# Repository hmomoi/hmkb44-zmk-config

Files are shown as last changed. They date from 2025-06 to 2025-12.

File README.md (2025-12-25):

# hmkb44 のページ

44キーのキーボード「hmkb44」の作成資材のページです。

主に、zmkファームウェアの管理と、KiCadの設計資材をおいています。

# 目指すキーボード
* 40%キーボード（EPOMAKER TH40を参考に）
* Bluetoothで接続
* LEDチカチカ
* charlieplexの実験

このくらいを目指して作ってます。
seeeduino_xiao_ble を使ってイロイロ実験してみたくて作成しました。
# レイアウト


# 回路


# 参照したnote
* https://note.com/pooh_polo/n/n2a34a922b4c8 (zmk firmwareの書き方)

# 参照したgithub
* https://github.com/te9no/zmk-config-GeaconSolstice/blob/main/boards/shields/GeaconSolstice/Solstice.keymap
* https://github.com/mctechnology17/zmk-config
* https://github.com/te9no/zmk-config-title72 （charlieplexのダイオードの向きが逆）
* https://github.com/HookyKB/round-robin-schematics (charlieplexのschematicが公開されている)
* https://github.com/mentako-ya/zmk-config-mtk64/tree/master (Layer rgbled widget を参考)

# キーマップ


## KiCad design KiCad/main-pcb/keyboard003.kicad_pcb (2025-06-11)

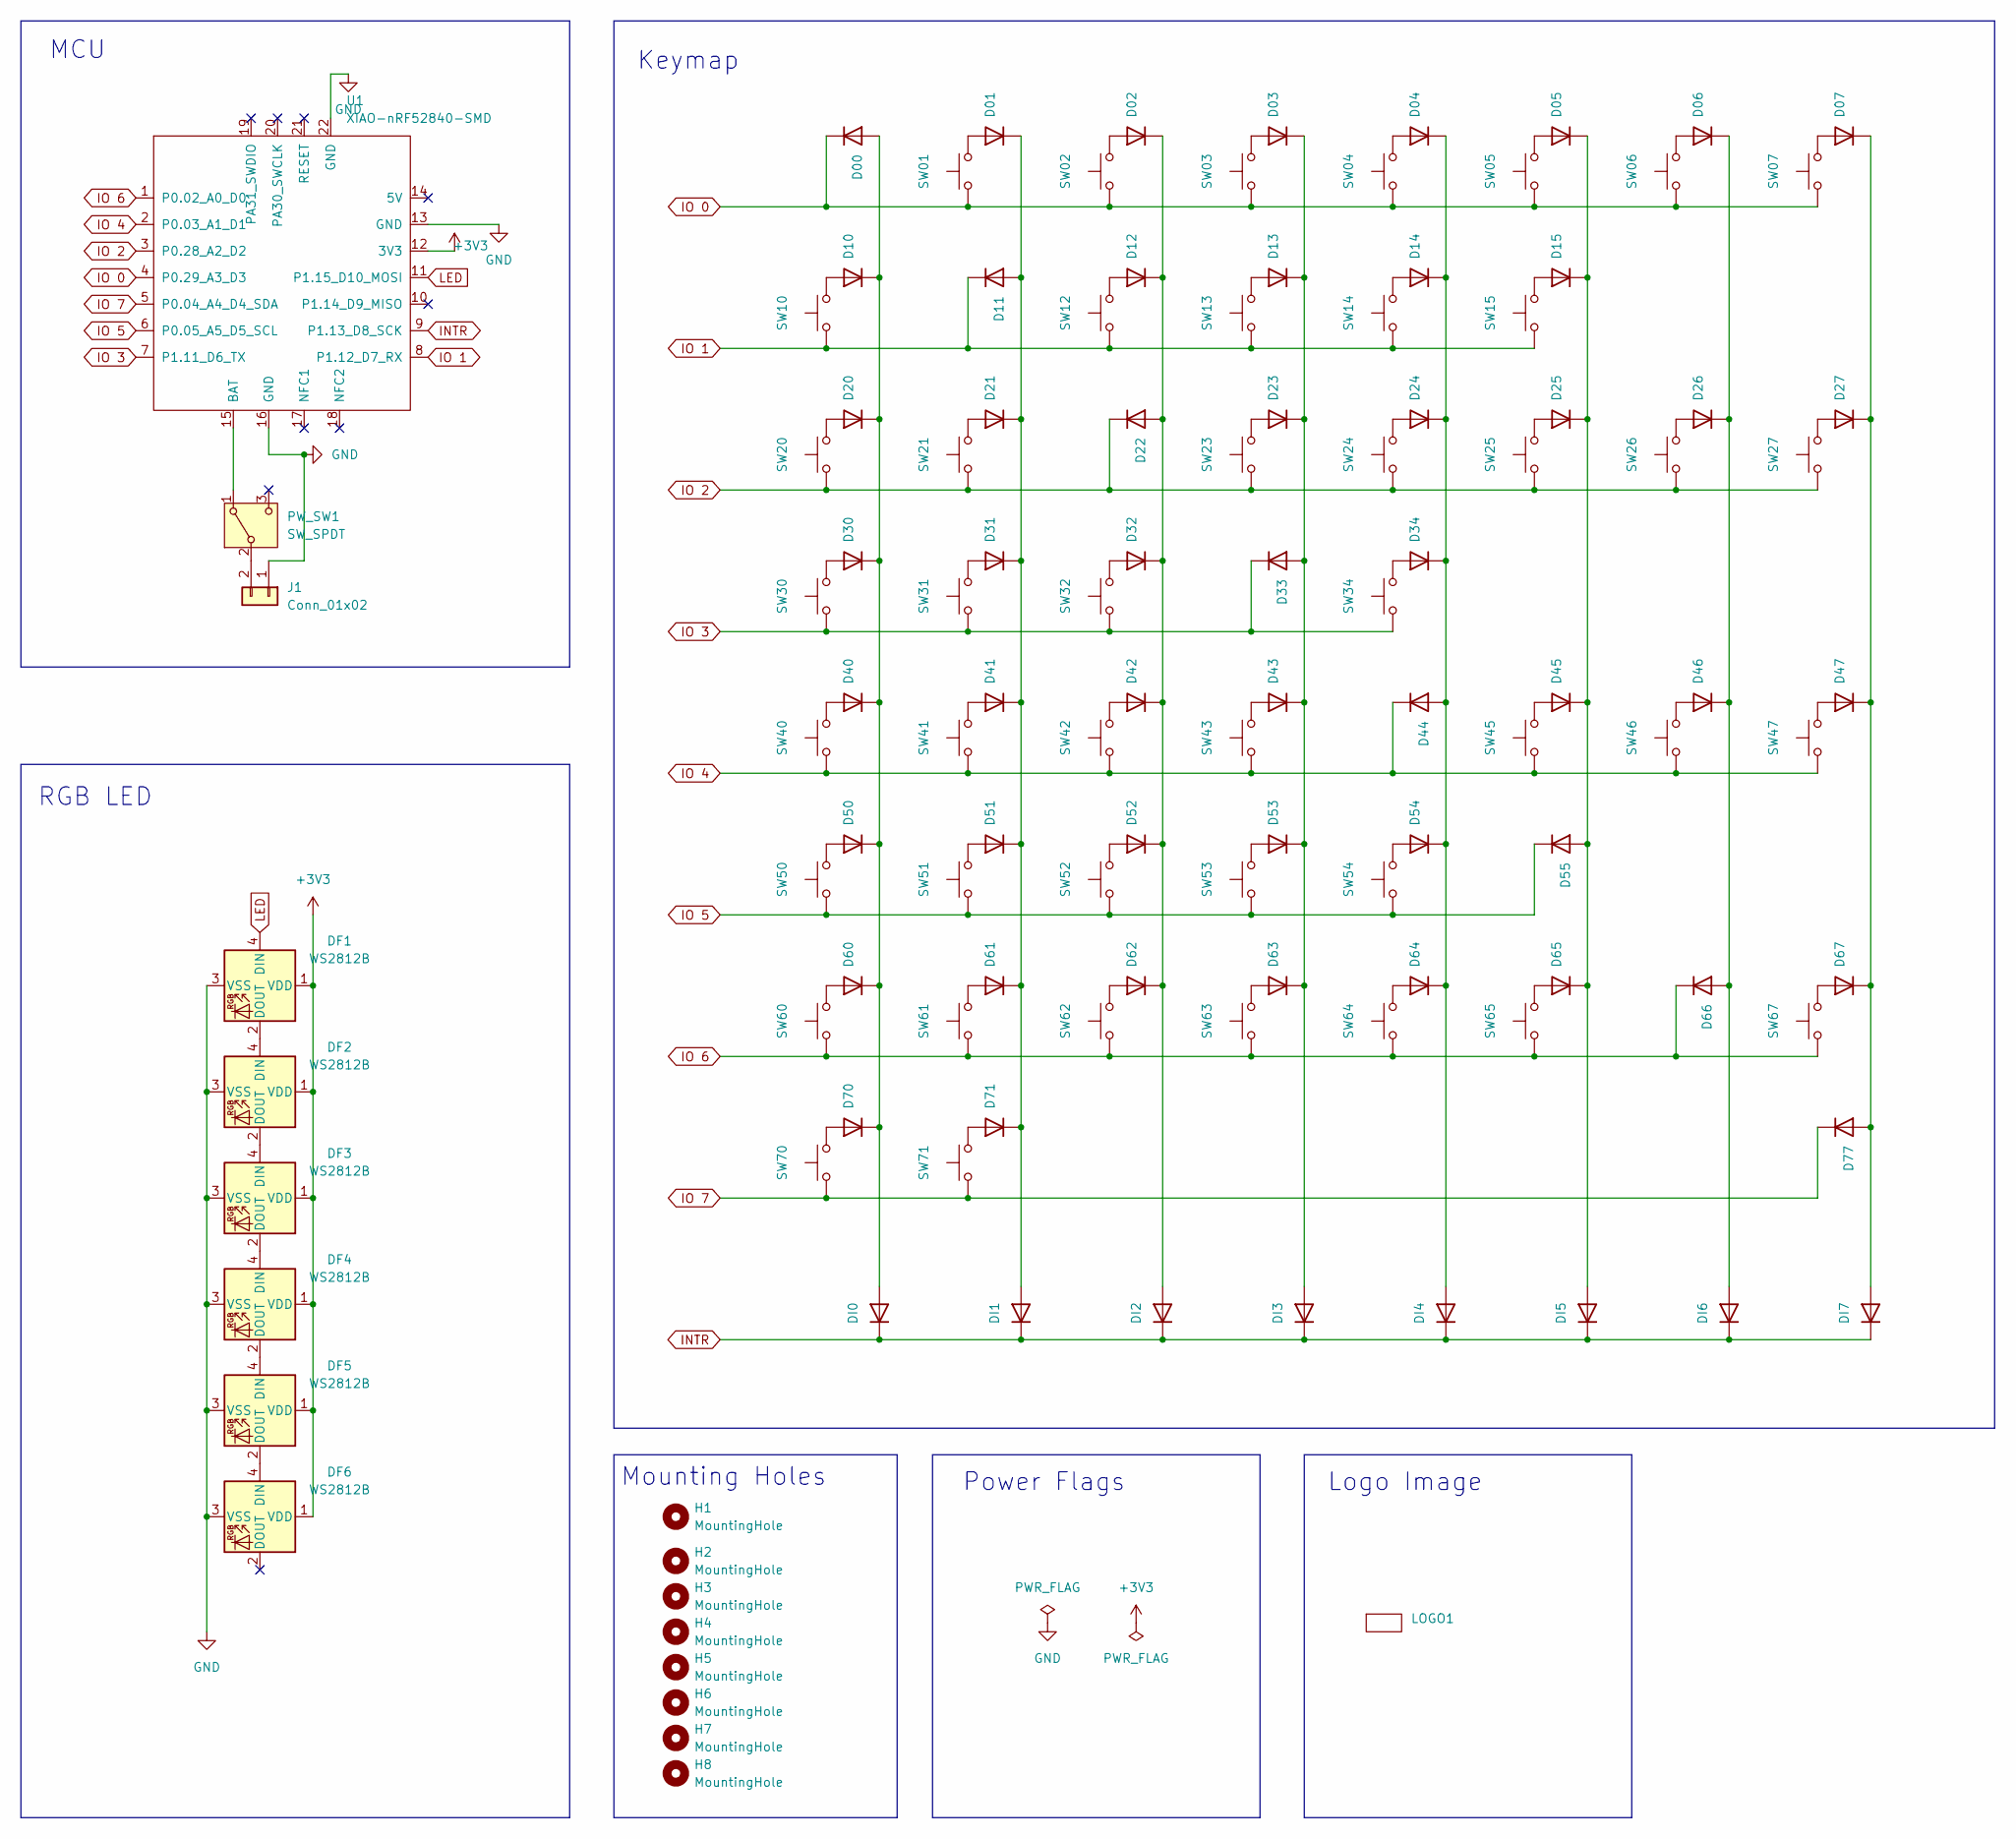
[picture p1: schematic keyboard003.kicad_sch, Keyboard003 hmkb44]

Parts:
D00, D01, D02, D03, D04, D05, D06, D07, D10, D11, D12, D13, D14, D15, D20, D21, D22, D23, D24, D25, D26, D27, D30, D31, D32, D33, D34, D40, D41, D42, D43, D44, D45, D46, D47, D50, D51, D52, D53, D54, D55, D60, D61, D62, D63, D64, D65, D66, D67, D70, D71, D77: 1N4148W; D_SOD-123; LCSC C81598
DF1, DF2, DF3, DF4, DF5, DF6: WS2812B; LED_WS2812B_PLCC4_5.0x5.0mm_P3.2mm
DI0, DI1, DI2, DI3, DI4, DI5, DI6, DI7: 1N4148W; D_SOD-123; LCSC C81598
H1, H2, H3, H4, H5, H6, H7, H8: MountingHole; MountingHole_2.2mm_M2
J1: Conn_01x02; JST_PH_S2B-PH-K_1x02_P2.00mm_Horizontal
LOGO1: LOGO
PW_SW1: SW_SPDT; SS-12D01G3
SW01, SW15: SW_Push; CherryMX_Hotswap_1.5u
SW02, SW03, SW04, SW05, SW06, SW07, SW10, SW12, SW13, SW14, SW21, SW23, SW24, SW25, SW26, SW27, SW30, SW31, SW32, SW41, SW42, SW43, SW45, SW46, SW47, SW50, SW51, SW52, SW53, SW64: SW_Push; CherryMX_Hotswap_1u
SW20, SW54: SW_Push; CherryMX_Hotswap_1.75u
SW34, SW63, SW65: SW_Push; CherryMX_Hotswap_2.25u
SW40, SW60, SW61, SW62, SW67, SW70, SW71: SW_Push; CherryMX_Hotswap_1.25u
U1: XIAO-nRF52840-SMD

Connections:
+3V3: DF1.1 (VDD), DF2.1 (VDD), DF3.1 (VDD), DF4.1 (VDD), DF5.1 (VDD), DF6.1 (VDD), U1.12 (3V3)
GND: DF1.3 (VSS), DF2.3 (VSS), DF3.3 (VSS), DF4.3 (VSS), DF5.3 (VSS), DF6.3 (VSS), J1.1, U1.13 (GND), U1.16 (GND), U1.22 (GND)
INTR: DI0.1 (K), DI1.1 (K), DI2.1 (K), DI3.1 (K), DI4.1 (K), DI5.1 (K), DI6.1 (K), DI7.1 (K), U1.9 (P1.13_D8_SCK)
IO 0: D00.1 (K), SW01.1, SW02.1, SW03.1, SW04.1, SW05.1, SW06.1, SW07.1, U1.4 (P0.29_A3_D3)
IO 1: D11.1 (K), SW10.1, SW12.1, SW13.1, SW14.1, SW15.1, U1.8 (P1.12_D7_RX)
IO 2: D22.1 (K), SW20.1, SW21.1, SW23.1, SW24.1, SW25.1, SW26.1, SW27.1, U1.3 (P0.28_A2_D2)
IO 3: D33.1 (K), SW30.1, SW31.1, SW32.1, SW34.1, U1.7 (P1.11_D6_TX)
IO 4: D44.1 (K), SW40.1, SW41.1, SW42.1, SW43.1, SW45.1, SW46.1, SW47.1, U1.2 (P0.03_A1_D1)
IO 5: D55.1 (K), SW50.1, SW51.1, SW52.1, SW53.1, SW54.1, U1.6 (P0.05_A5_D5_SCL)
IO 6: D66.1 (K), SW60.1, SW61.1, SW62.1, SW63.1, SW64.1, SW65.1, SW67.1, U1.1 (P0.02_A0_D0)
IO 7: D77.1 (K), SW70.1, SW71.1, U1.5 (P0.04_A4_D4_SDA)
LED: DF1.4 (DIN), U1.11 (P1.15_D10_MOSI)
unnamed: D00.2 (A), D10.1 (K), D20.1 (K), D30.1 (K), D40.1 (K), D50.1 (K), D60.1 (K), D70.1 (K), DI0.2 (A)
unnamed: D01.2 (A), SW01.2
unnamed: D01.1 (K), D11.2 (A), D21.1 (K), D31.1 (K), D41.1 (K), D51.1 (K), D61.1 (K), D71.1 (K), DI1.2 (A)
unnamed: D02.2 (A), SW02.2
unnamed: D02.1 (K), D12.1 (K), D22.2 (A), D32.1 (K), D42.1 (K), D52.1 (K), D62.1 (K), DI2.2 (A)
unnamed: D03.2 (A), SW03.2
unnamed: D03.1 (K), D13.1 (K), D23.1 (K), D33.2 (A), D43.1 (K), D53.1 (K), D63.1 (K), DI3.2 (A)
unnamed: D04.2 (A), SW04.2
unnamed: D04.1 (K), D14.1 (K), D24.1 (K), D34.1 (K), D44.2 (A), D54.1 (K), D64.1 (K), DI4.2 (A)
unnamed: D05.2 (A), SW05.2
unnamed: D05.1 (K), D15.1 (K), D25.1 (K), D45.1 (K), D55.2 (A), D65.1 (K), DI5.2 (A)
unnamed: D06.2 (A), SW06.2
unnamed: D06.1 (K), D26.1 (K), D46.1 (K), D66.2 (A), DI6.2 (A)
unnamed: D07.2 (A), SW07.2
unnamed: D07.1 (K), D27.1 (K), D47.1 (K), D67.1 (K), D77.2 (A), DI7.2 (A)
unnamed: D10.2 (A), SW10.2
unnamed: D12.2 (A), SW12.2
unnamed: D13.2 (A), SW13.2
unnamed: D14.2 (A), SW14.2
unnamed: D15.2 (A), SW15.2
unnamed: D20.2 (A), SW20.2
unnamed: D21.2 (A), SW21.2
unnamed: D23.2 (A), SW23.2
unnamed: D24.2 (A), SW24.2
unnamed: D25.2 (A), SW25.2
unnamed: D26.2 (A), SW26.2
unnamed: D27.2 (A), SW27.2
unnamed: D30.2 (A), SW30.2
unnamed: D31.2 (A), SW31.2
unnamed: D32.2 (A), SW32.2
unnamed: D34.2 (A), SW34.2
unnamed: D40.2 (A), SW40.2
unnamed: D41.2 (A), SW41.2
unnamed: D42.2 (A), SW42.2
unnamed: D43.2 (A), SW43.2
unnamed: D45.2 (A), SW45.2
unnamed: D46.2 (A), SW46.2
unnamed: D47.2 (A), SW47.2
unnamed: D50.2 (A), SW50.2
unnamed: D51.2 (A), SW51.2
unnamed: D52.2 (A), SW52.2
unnamed: D53.2 (A), SW53.2
unnamed: D54.2 (A), SW54.2
unnamed: D60.2 (A), SW60.2
unnamed: D61.2 (A), SW61.2
unnamed: D62.2 (A), SW62.2
unnamed: D63.2 (A), SW63.2
unnamed: D64.2 (A), SW64.2
unnamed: D65.2 (A), SW65.2
unnamed: D67.2 (A), SW67.2
unnamed: D70.2 (A), SW70.2
unnamed: D71.2 (A), SW71.2
unnamed: DF1.2 (DOUT), DF2.4 (DIN)
unnamed: DF2.2 (DOUT), DF3.4 (DIN)
unnamed: DF3.2 (DOUT), DF4.4 (DIN)
unnamed: DF4.2 (DOUT), DF5.4 (DIN)
unnamed: DF5.2 (DOUT), DF6.4 (DIN)
unnamed: J1.2, PW_SW1.2 (B)
unnamed: PW_SW1.1 (A), U1.15 (BAT)

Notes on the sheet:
MCU
Mounting Holes
RGB LED
Logo Image
Keymap
Power Flags

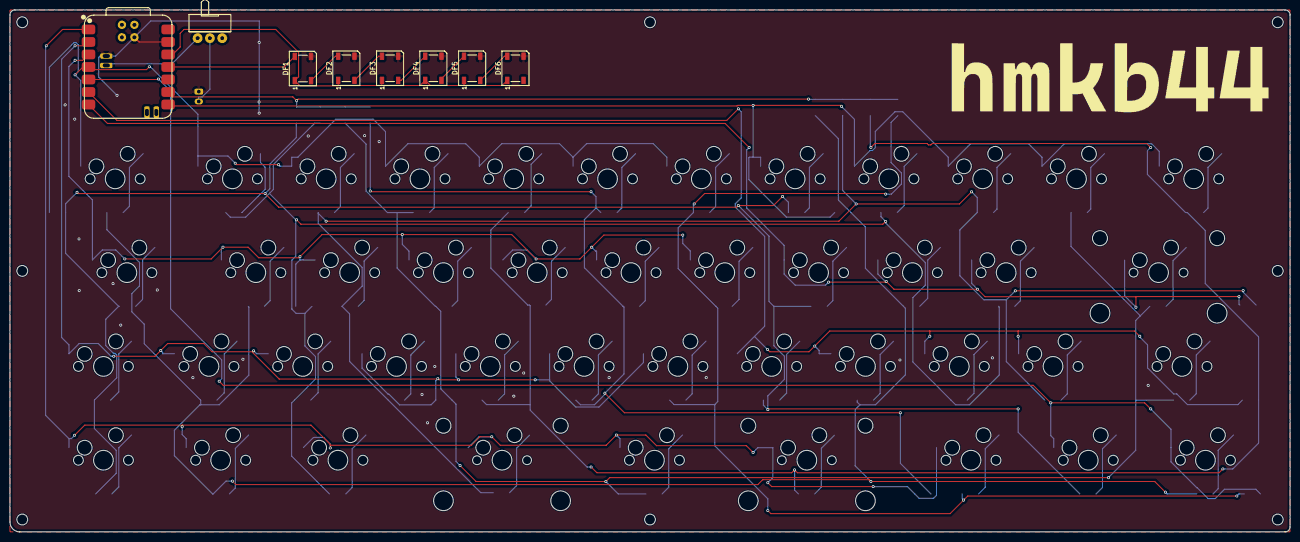
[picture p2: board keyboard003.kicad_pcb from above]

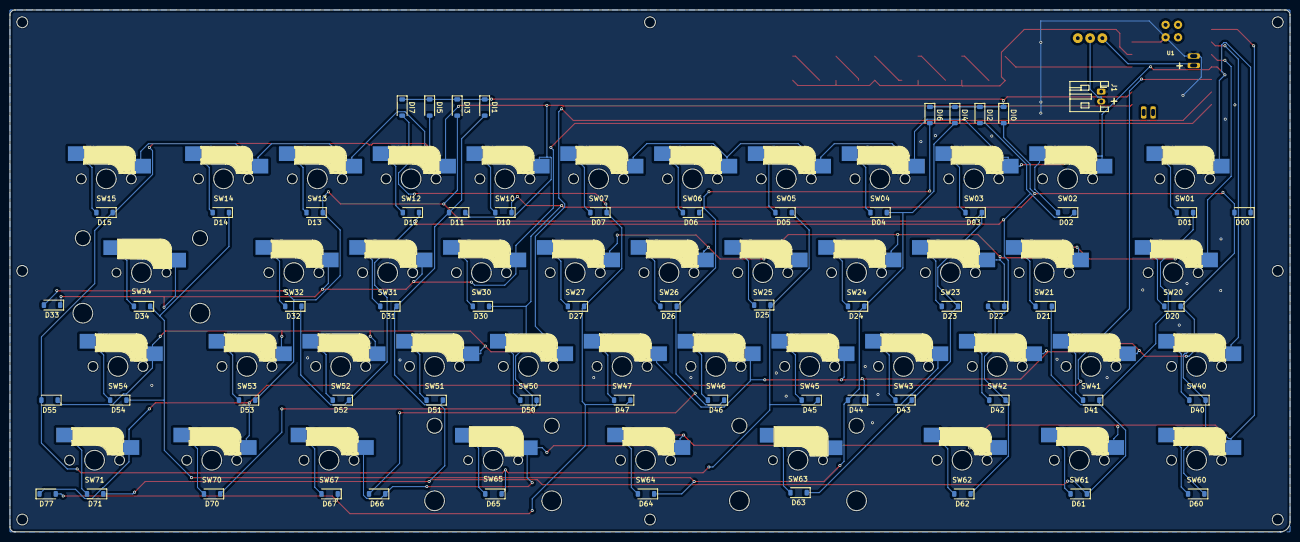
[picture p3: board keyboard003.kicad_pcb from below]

Board: 2 copper layers, 260.0 x 106.0 mm, 122 parts (61 on the bottom side), 71 nets.

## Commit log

2025-05-22 testコミット
2025-05-22 サンプルファイル
2025-05-23 error対応
2025-05-23 エラー対応２
2025-05-23 エラー対応３
2025-05-23 エラー対応４
2025-05-23 エラー対応５
2025-05-23 エラー対応6
2025-05-23 エラー対応７
2025-05-23 エラー対応8
2025-05-23 エラー対応９
2025-05-23 エラー対応10
2025-05-23 tab esc change
2025-05-26 layer button change 60
2025-05-27 62
    README.mdの変更
    某なれはてさんのページへのリンク追加
2025-06-10 95 改行コードをLFに変更
